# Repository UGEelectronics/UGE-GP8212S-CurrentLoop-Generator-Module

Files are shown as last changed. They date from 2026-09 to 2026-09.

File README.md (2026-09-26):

# UGE GP8212S 4–20 mA Current Loop Generator Module

Compact **I²C-controlled** analog output board based on the Linearin **GP8212S-TC50-EW** (15-bit DAC → industrial **0 / 4–20 mA** current loop).

**[Open interactive BOM ↗](https://ugeelectronics.github.io/UGE-GP8212S-CurrentLoop-Generator-Module/GP8212SBOM.html)** — browser BOM for soldering / identifying parts (do not use the GitHub `.html` file viewer).

<p align="center">
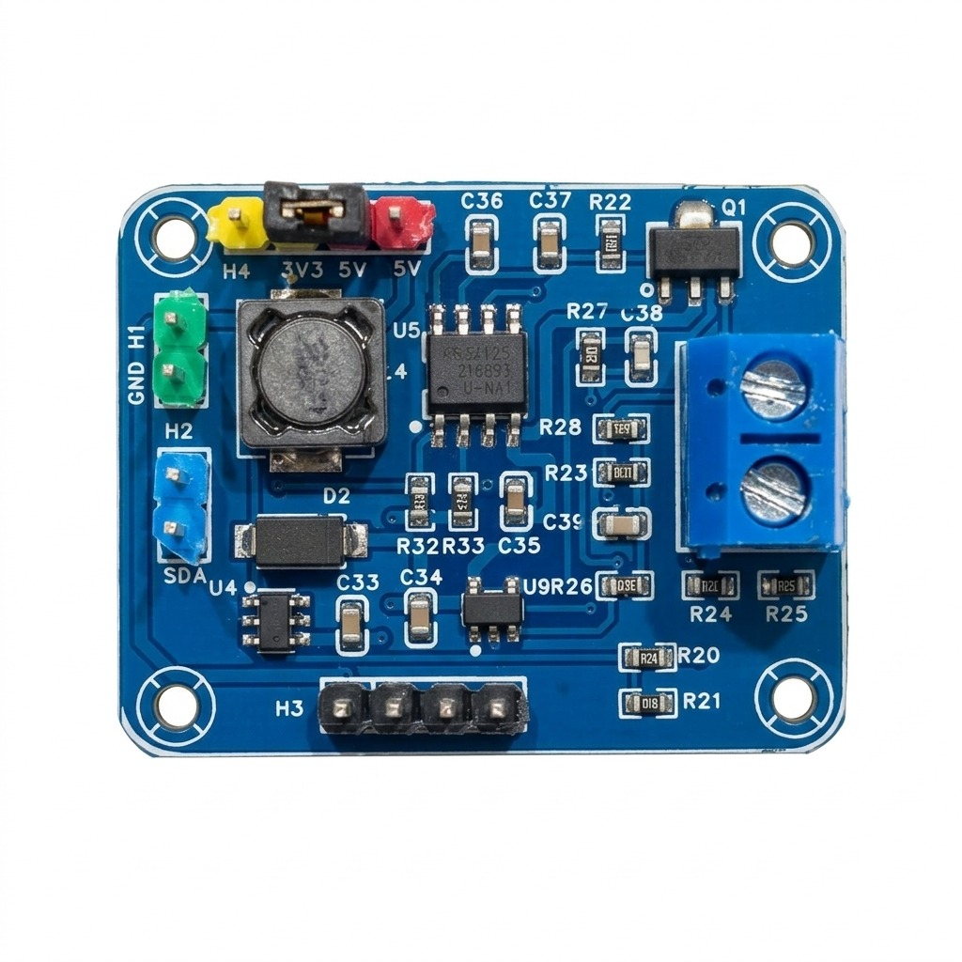
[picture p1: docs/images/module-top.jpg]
UGE GP8212S module top view
  
</p>

<p align="center">
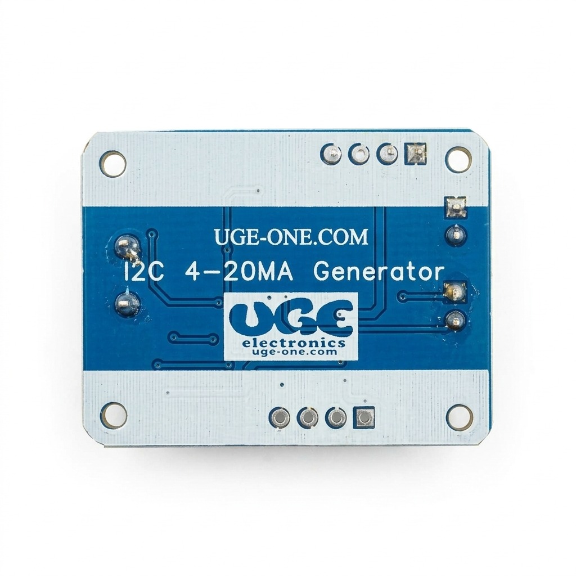
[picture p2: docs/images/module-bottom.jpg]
UGE GP8212S module bottom — I2C 4-20mA Generator
  
</p>

| | |
|---|---|
| **Chip** | GP8212S-TC50-EW (ESOP-8), 15-bit I²C |
| **Output** | 0–25 mA full scale (typical with Rs = 100 Ω); use 4–20 mA for industrial loops |
| **Interface** | I²C address **0x58**, logic **2.7–5.5 V** (Arduino & ESP32 friendly) |
| **Module power** | **5 V** input → onboard **MT3608** boost → ~**12 V** for the DAC |
| **MCU examples** | Arduino / ESP32 library in this repo; STM32 bit-bang reference included |
| **Interactive BOM** | **[Open in browser](https://ugeelectronics.github.io/UGE-GP8212S-CurrentLoop-Generator-Module/GP8212SBOM.html)** |
| **Buy the full module** | **[uge-one.com](https://uge-one.com/product/gp8212s-4-20-ma-current-loop-generator-transmitter-i2c-module/)** |

---

## Buy

| Item | Link |
|---|---|
| **Full module (assembled)** | [uge-one.com — GP8212S 4–20 mA I2C module](https://uge-one.com/product/gp8212s-4-20-ma-current-loop-generator-transmitter-i2c-module/) |
| **GP8212S chip only** | [uge-one.com — GP8212S-TC50-EW](https://uge-one.com/product/gp8212s-tc50-ew-15-bit-i%c2%b2c-to-4-20ma-dac-ic-esop-8/) |
| **Empty bare PCB** | [uge-one.com — PCB for I2C 4–20 mA generator](https://uge-one.com/product/pcb-for-i2c-4-20ma-generator-module/) |
| **Interactive BOM** | **[Open live BOM](https://ugeelectronics.github.io/UGE-GP8212S-CurrentLoop-Generator-Module/GP8212SBOM.html)** |

SKU of the full module: **GP8212S-MOD**. More products: [UGE Electronics](https://uge-one.com/).

---

## Repository layout

```text
software/GP8212S/     Arduino & ESP32 library + examples
docs/                 GitHub Pages site + interactive BOM + images
hardware/             Link to the live BOM (GitHub code view cannot render HTML)
stm32_reference/      Original STM32F10x bit-bang I²C (MyI2C)
```

---

## Quick start (Arduino / ESP32)

### 1. Install the library

**Option A — manual**

1. Download this repository (Code → Download ZIP) or clone it.
2. Copy the folder `software/GP8212S` into your Arduino libraries directory:
   - Windows: `Documents\Arduino\libraries\GP8212S`
   - macOS: `~/Documents/Arduino/libraries/GP8212S`
   - Linux: `~/Arduino/libraries/GP8212S`
3. Restart the Arduino IDE.

**Option B — ZIP**

Sketch → Include Library → Add .ZIP Library… and select a ZIP that contains the `GP8212S` folder (with `library.properties` at its root).

### 2. Wire the module

<p align="center">
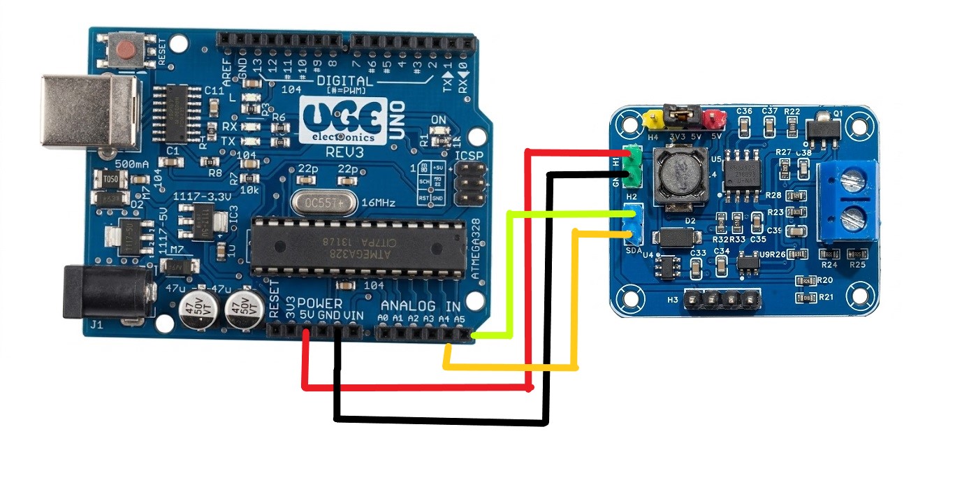
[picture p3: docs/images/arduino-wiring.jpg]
Arduino Uno wired to UGE GP8212S module
  
</p>

| Module | Arduino Uno / Nano | ESP32 (typical) | Notes |
|---|---|---|---|
| **5 V** (H1) | 5 V | 5 V-capable supply | Powers MT3608 → ~12 V for the DAC |
| **GND** (H1) | GND | GND | Common ground |
| **SCL** (H2) | A5 | GPIO 22 | I²C clock |
| **SDA** (H2) | A4 | GPIO 21 | I²C data |
| **IOUT** (blue terminal) | — | — | Loop output — connect load / meter here |

- Share **GND** between MCU and module.
- Do **not** feed the GP8212S chip `VCC` pin from USB 5 V directly — use the module’s **5 V** input so the MT3608 can boost to ~12 V.
- I²C works at **3.3 V** (ESP32) or **5 V** (classic Arduino).

<p align="center">
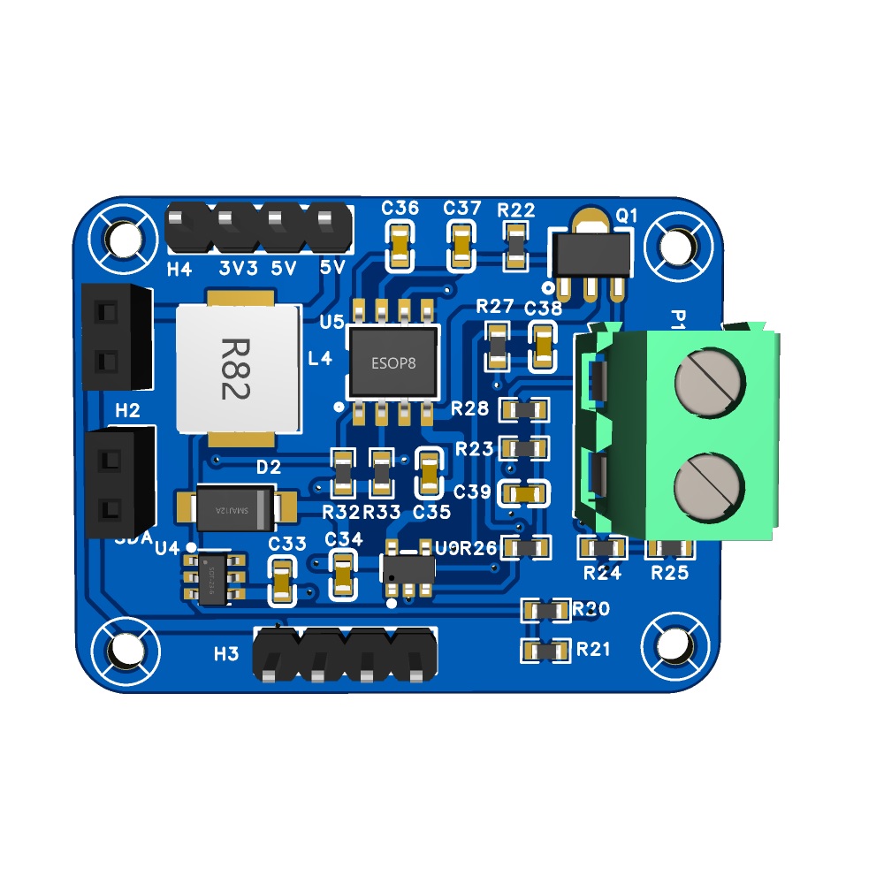
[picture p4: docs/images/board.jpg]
Assembled module overview
  
</p>

### 3. Minimal sketch

```cpp
#include <Wire.h>
#include <GP8212S.h>

GP8212S dac;  // I2C 0x58, 25 mA full scale (Rs = 100 Ω)

void setup() {
  Serial.begin(115200);

#if defined(ESP32)
  if (dac.begin(21, 22) != 0) {   // SDA, SCL
#else
  if (dac.begin() != 0) {
#endif
    Serial.println("GP8212S not found");
    while (true) {}
  }

  dac.setCurrent_mA(12.0);     // milliamps
  // After one-time calibration, paste your line from "apply":
  // dac.calibrate4_20(5200, 26200);
  // dac.setPercent4_20(50);   // 0–100% of 4–20 mA span
  // dac.setDAC(0x3D70);       // raw 15-bit code
}

void loop() {}
```

### 4. Examples

After install: **File → Examples → GP8212S**

| Example | What it does |
|---|---|
| **CurrentSweep** | Sweeps 4 → 20 → 4 mA |
| **SetAndStore** | Set mA from Serial; optional NVM `store()` |
| **Calibrate4_20** | Interactive two-point calibration with a meter |

---

## API overview

| Method | Description |
|---|---|
| `begin(sda, scl, freq)` | Init I²C and probe (returns `0` on ACK) |
| `setCurrent_mA(mA)` | Output current in mA (0 … full scale) |
| `setPercent4_20(pct)` | 0% → 4 mA, 100% → 20 mA |
| `setDAC(code)` | Raw 15-bit code `0 … 0x7FFF` |
| `calibrate4_20(dac4, dac20)` | Use measured codes for accurate 4–20 mA |
| `store(sda, scl)` | Save last DAC value in chip NVM (survives power-off) |

Ideal codes with **Rs = 100 Ω** (0–25 mA full scale):

| Current | Approx. DAC |
|---|---|
| 4 mA | 5243 (`0x147A`) |
| 12 mA | 15728 (`0x3D70`) |
| 20 mA | 26214 (`0x6666`) |
| 25 mA | 32767 (`0x7FFF`) |

Datasheet: `IOUT = (2.5 V / Rs) × (DATA / 0x7FFF)`.

---

## Calibration (recommended — once per board)

You do **not** repeat this on every power-on. Run it once, then paste `dac.calibrate4_20(...)` into your sketches.

### What you need

- Arduino (or ESP32) + this module wired as above  
- **~330 Ω** load on the blue **IOUT** terminal (**1 W preferred**)  
- DMM measuring the **actual loop current** through that resistor  

### Steps

1. Upload **Examples → GP8212S → Calibrate4_20**.
2. Open **Serial Monitor** at **115200** (line ending: **Newline**).
3. Type **`4`**  
   Read the meter (example: **8.08 mA**).  
   Type **`M 8.08`** — the sketch rescales to 4 mA and **auto-saves** the 4 mA point.
4. Type **`20`**  
   Read the meter (example: **25.63 mA**).  
   Type **`M 25.63`** — rescales to 20 mA and **auto-saves** the 20 mA point.
5. Type **`apply`**. You get a line like:

```cpp
dac.calibrate4_20(5200, 26200);
```

6. Put that line in `setup()` **after** `dac.begin(...)` in all future code for this board.

Optional fine trim before `apply`: `+++` `---` (±2000), `++` `--` (±500), `+` `-` (±50), `]` `[` (±5). Commands are case-insensitive (`m` / `M`).
---

## Hardware & soldering

<p align="center">
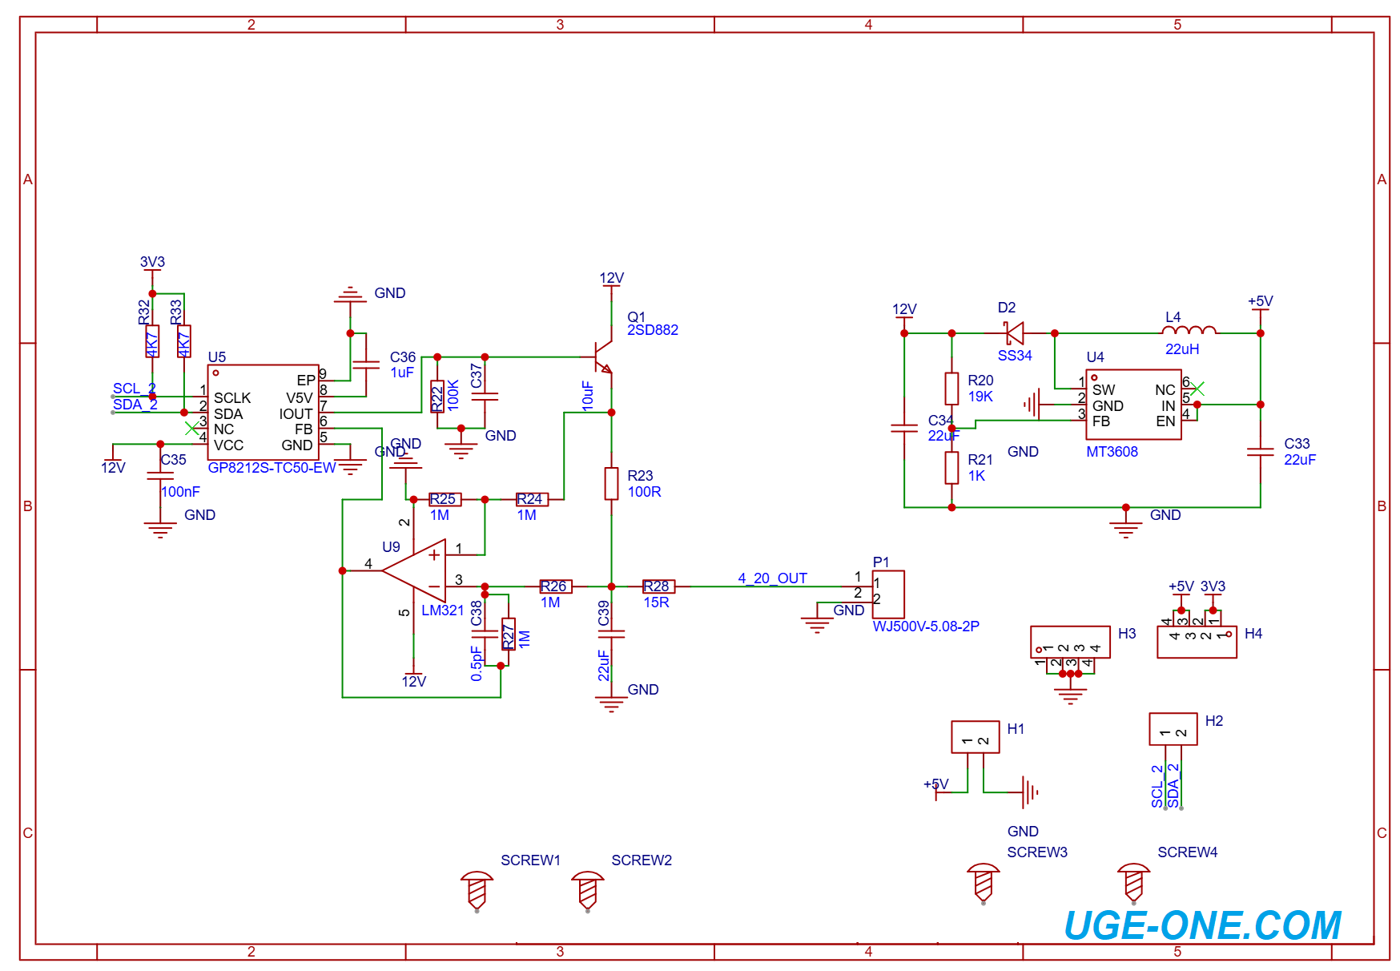
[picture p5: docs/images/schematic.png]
GP8212S module schematic
  
</p>

### Interactive BOM (opens in the browser)

GitHub’s file viewer only shows HTML **source**. Use one of these instead:

| | |
|---|---|
| **Live page (recommended)** | [Open interactive BOM](https://ugeelectronics.github.io/UGE-GP8212S-CurrentLoop-Generator-Module/GP8212SBOM.html) |
| **Docs home** | [ugeelectronics.github.io/…/](https://ugeelectronics.github.io/UGE-GP8212S-CurrentLoop-Generator-Module/) |
| **Offline** | Download [`docs/GP8212SBOM.html`](docs/GP8212SBOM.html) and double-click it |

> **First-time Pages setup (repo admins) — required once:**  
> 1. Open **Settings → Pages**  
> 2. Under **Build and deployment → Source**, choose **Deploy from a branch**  
> 3. Branch: **main**, folder: **/docs** → **Save**  
> 4. Wait about a minute, then open the live BOM link above.

---

## STM32 reference

[`stm32_reference/MyI2C.c`](stm32_reference/MyI2C.c) is the original **STM32F10x open-drain bit-bang I²C** layer (no high-level DAC API). The Arduino library replaces that with `Wire` and implements the GP8212S register write / store sequence.

---

## Notes & limits

- Default I²C address: **`0x58`**.
- Chip `VCC` range per datasheet: **9–36 V**; this module uses ~**12 V** from MT3608 after **5 V** input.
- Max load resistance shrinks at 12 V vs 24 V — keep calibration / field loads in the **~220–330 Ω** range unless you raise the boost voltage within safe design limits.
- There is **no official Arduino library named GP8212S** from the chip vendor; DFRobot’s [GP8XXX](https://github.com/DFRobot/DFRobot_GP8XXX) covers related parts (e.g. GP8211S / GP8302) but not this module. Use **UGE `GP8212S`** here.

---

## License

MIT — see [LICENSE](LICENSE).  
© 2026 UGE Electronics — [uge-one.com](https://uge-one.com/)

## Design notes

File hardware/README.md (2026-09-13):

# Hardware

The interactive BOM is published as a **live web page** (GitHub does not render `.html` files in the code viewer).

**Open here:**  
https://ugeelectronics.github.io/UGE-GP8212S-CurrentLoop-Generator-Module/GP8212SBOM.html

Source file in this repo: [`docs/GP8212SBOM.html`](../docs/GP8212SBOM.html)  
(You can also download that file and open it locally in any browser.)

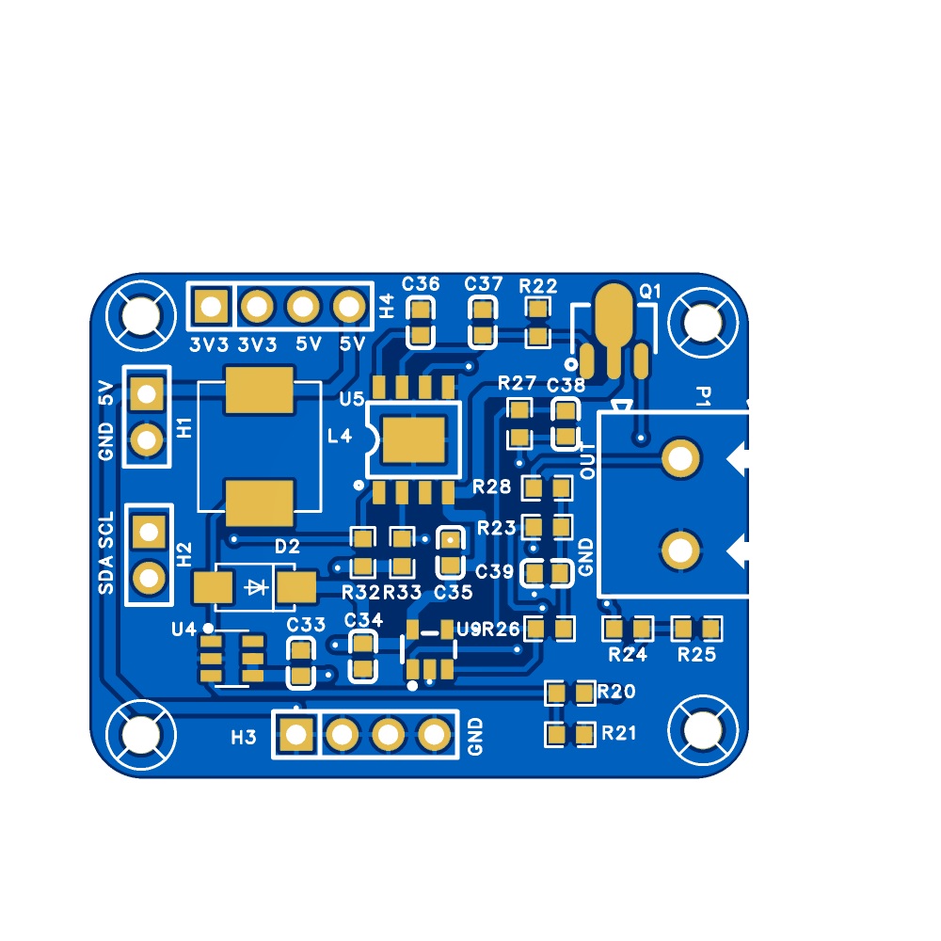
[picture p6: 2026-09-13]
docs/images/pcb-top.jpg

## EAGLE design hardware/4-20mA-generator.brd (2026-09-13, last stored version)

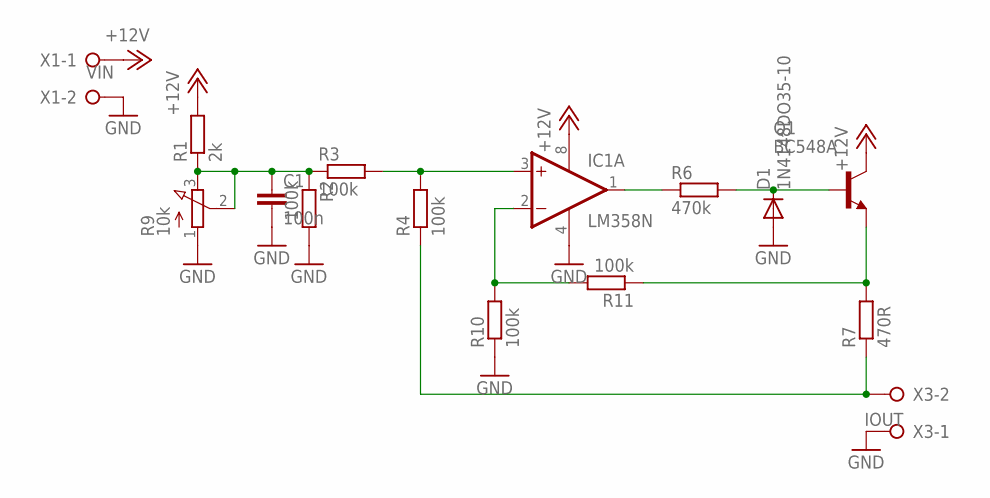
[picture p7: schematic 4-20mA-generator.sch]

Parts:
C1: 100n; C050-024X044
D1: 1N4148DO35-10; DO35-10
IC1: LM358N; DIL08
Q1: BC548A; TO92-EBC
R1: 2k; 0207/7
R2, R3, R4, R10, R11: 100k; 0207/7
R6: 470k; 0207/7
R7: 470R; 0207/7
R9: 10k; 3RP/1610N
X1: VIN; W237-132
X3: IOUT; W237-132

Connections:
+12V: IC1.8 (V+), Q1.C, R1.2, X1.1
GND: C1.2, D1.A, IC1.4 (V-), R2.2, R9.1 (A), R10.1, X1.2, X3.1
unnamed: C1.1, R1.1, R2.1, R3.1, R9.2 (S), R9.3 (E)
unnamed: IC1.2 (-IN), R10.2, R11.2
unnamed: IC1.1 (OUT), R6.1
unnamed: D1.C, Q1.B, R6.2
unnamed: Q1.E, R7.2, R11.1
unnamed: R4.1, R7.1, X3.2
unnamed: IC1.3 (+IN), R3.2, R4.2

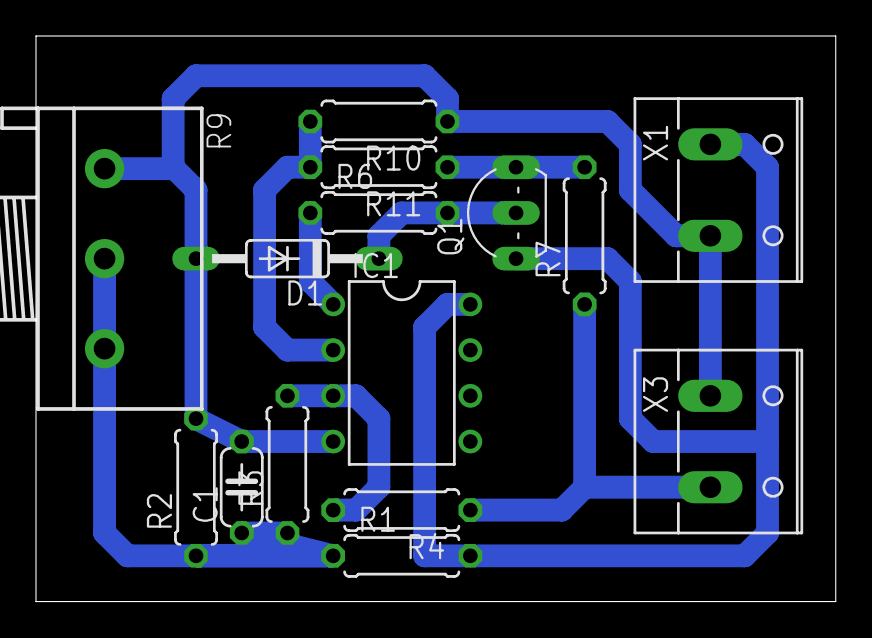
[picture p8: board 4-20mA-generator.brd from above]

Board: 2 copper layers, 44.4 x 31.4 mm, 15 parts (0 on the bottom side), 9 nets.

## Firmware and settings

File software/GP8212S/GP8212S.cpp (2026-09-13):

/*!
 * @file GP8212S.cpp
 * @brief Arduino / ESP32 driver for Linearin GP8212S
 */

#include "GP8212S.h"

const float GP8212S::FULL_SCALE_MA = 25.0f;

// Register / store timing constants (same GP8xxx family protocol as DFRobot)
static const uint8_t REG_DAC = 0x02;
static const uint8_t STORE_HEAD = 0x02;   // 3-bit preamble
static const uint8_t STORE_ADDR = 0x10;
static const uint8_t STORE_CMD1 = 0x03;
static const uint8_t STORE_CMD2 = 0x00;
static const uint8_t STORE_DELAY_MS = 10;

static const uint8_t I2C_HALF_US = 5;

GP8212S::GP8212S(uint8_t deviceAddr, TwoWire *wire, float fullScaleMa)
    : _wire(wire),
      _addr(deviceAddr),
      _fullScaleMa(fullScaleMa),
      _lastDac(0),
      _calEnabled(false),
      _cal4(0),
      _cal20(0),
      _sdaPin(-1),
      _sclPin(-1) {}

int GP8212S::begin(int sda, int scl, uint32_t freq) {
  _sdaPin = sda;
  _sclPin = scl;

#if defined(ESP32) || defined(ESP8266) || defined(ARDUINO_ARCH_ESP32)
  if (sda >= 0 && scl >= 0) {
    _wire->begin(sda, scl, freq);
  } else {
    _wire->begin();
    _wire->setClock(freq);
  }
#else
  (void)sda;
  (void)scl;
  _wire->begin();
  _wire->setClock(freq);
#endif

  _wire->beginTransmission(_addr);
  return _wire->endTransmission();
}

bool GP8212S::isConnected() {
  _wire->beginTransmission(_addr);
  return _wire->endTransmission() == 0;
}

uint16_t GP8212S::mAToDAC(float mA) const {
  if (mA <= 0.0f) {
    return 0;
  }
  if (mA >= _fullScaleMa) {
    return DAC_MAX;
  }
  return (uint16_t)((mA / _fullScaleMa) * (float)DAC_MAX + 0.5f);
}

float GP8212S::dacTo_mA(uint16_t code) const {
  if (code > DAC_MAX) {
    code = DAC_MAX;
  }
  return ((float)code / (float)DAC_MAX) * _fullScaleMa;
}

void GP8212S::calibrate4_20(uint16_t dacAt4mA, uint16_t dacAt20mA) {
  if (dacAt4mA >= dacAt20mA || dacAt20mA > DAC_MAX) {
    _calEnabled = false;
    return;
  }
  _cal4 = dacAt4mA;
  _cal20 = dacAt20mA;
  _calEnabled = true;
}

void GP8212S::clearCalibration() {
  _calEnabled = false;
}

bool GP8212S::writeDACRegister(uint16_t shifted16) {
  // Protocol: START | ADDR+W | REG=0x02 | DATA_LOW | DATA_HIGH | STOP
  // 15-bit payload is left-shifted by 1 before the two data bytes.
  uint8_t lo = (uint8_t)(shifted16 & 0xFF);
  uint8_t hi = (uint8_t)(shifted16 >> 8);

  _wire->beginTransmission(_addr);
  _wire->write(REG_DAC);
  _wire->write(lo);
  _wire->write(hi);
  return _wire->endTransmission() == 0;
}

bool GP8212S::setDAC(uint16_t code) {
  if (code > DAC_MAX) {
    code = DAC_MAX;
  }
  _lastDac = code;
  // Same packing as GP8211S / GP8xxx 15-bit parts
  return writeDACRegister((uint16_t)(code << 1));
}

uint16_t GP8212S::setCurrent_mA(float mA) {
  uint16_t code;

  if (_calEnabled && mA >= 4.0f && mA <= 20.0f) {
    // Linear map 4–20 mA onto measured DAC codes
    float t = (mA - 4.0f) / 16.0f;
    code = (uint16_t)(_cal4 + t * (float)(_cal20 - _cal4) + 0.5f);
  } else {
    code = mAToDAC(mA);
  }

  if (!setDAC(code)) {
    return 0xFFFF;
  }
  return code;
}

uint16_t GP8212S::setPercent4_20(float percent) {
  if (percent < 0.0f) {
    percent = 0.0f;
  }
  if (percent > 100.0f) {
    percent = 100.0f;
  }
  return setCurrent_mA(4.0f + percent * 0.16f);
}

// ---- NVM store (datasheet §3.2.4) — bit-bang on the same pins ----

void GP8212S::storeStart(int scl, int sda) {
  digitalWrite(scl, HIGH);
  digitalWrite(sda, HIGH);
  delayMicroseconds(I2C_HALF_US);
  digitalWrite(sda, LOW);
  delayMicroseconds(I2C_HALF_US);
  digitalWrite(scl, LOW);
  delayMicroseconds(I2C_HALF_US);
}

void GP8212S::storeStop(int scl, int sda) {
  digitalWrite(sda, LOW);
  delayMicroseconds(I2C_HALF_US);
  digitalWrite(scl, HIGH);
  delayMicroseconds(I2C_HALF_US);
  digitalWrite(sda, HIGH);
  delayMicroseconds(I2C_HALF_US);
}

uint8_t GP8212S::storeSendByte(int scl, int sda, uint8_t data, uint8_t bits,
                               bool expectAck) {
  for (int i = bits - 1; i >= 0; i--) {
    digitalWrite(sda, (data & (1 << i)) ? HIGH : LOW);
    delayMicroseconds(I2C_HALF_US);
    digitalWrite(scl, HIGH);
    delayMicroseconds(I2C_HALF_US);
    digitalWrite(scl, LOW);
    delayMicroseconds(I2C_HALF_US);
  }

  if (!expectAck) {
    digitalWrite(sda, LOW);
    digitalWrite(scl, HIGH);
    delayMicroseconds(I2C_HALF_US);
    digitalWrite(scl, LOW);
    return 0;
  }

  pinMode(sda, INPUT_PULLUP);
  delayMicroseconds(I2C_HALF_US);
  digitalWrite(scl, HIGH);
  delayMicroseconds(I2C_HALF_US);
  uint8_t ack = digitalRead(sda);
  digitalWrite(scl, LOW);
  delayMicroseconds(I2C_HALF_US);
  pinMode(sda, OUTPUT);
  return ack;
}

void GP8212S::store(int sda, int scl) {
  if (sda < 0) {
    sda = _sdaPin;
  }
  if (scl < 0) {
    scl = _sclPin;
  }
  if (sda < 0 || scl < 0) {
    // Fall back to Arduino default macros when pins were never passed to begin()
#if defined(SDA) && defined(SCL)
    sda = SDA;
    scl = SCL;
#else
    return;
#endif
  }

#if defined(ESP32)
  _wire->~TwoWire();
#elif !defined(ESP8266)
  _wire->end();
#endif

  pinMode(scl, OUTPUT);
  pinMode(sda, OUTPUT);
  digitalWrite(scl, HIGH);
  digitalWrite(sda, HIGH);

  // Sequence from datasheet / GP8xxx store timing
  storeStart(scl, sda);
  storeSendByte(scl, sda, STORE_HEAD, 3, false);
  storeStop(scl, sda);

  storeStart(scl, sda);
  storeSendByte(scl, sda, STORE_ADDR);
  storeSendByte(scl, sda, STORE_CMD1);
  storeStop(scl, sda);

  storeStart(scl, sda);
  storeSendByte(scl, sda, (uint8_t)(_addr << 1));
  for (int i = 0; i < 8; i++) {
    storeSendByte(scl, sda, STORE_CMD2);
  }
  storeStop(scl, sda);

  delay(STORE_DELAY_MS);

  storeStart(scl, sda);
  storeSendByte(scl, sda, STORE_HEAD, 3, false);
  storeStop(scl, sda);

  storeStart(scl, sda);
  storeSendByte(scl, sda, STORE_ADDR);
  storeSendByte(scl, sda, STORE_CMD2);
  storeStop(scl, sda);

  // Restore hardware I2C
#if defined(ESP32) || defined(ESP8266) || defined(ARDUINO_ARCH_ESP32)
  if (_sdaPin >= 0 && _sclPin >= 0) {
    _wire->begin(_sdaPin, _sclPin);
  } else {
    _wire->begin();
  }
#else
  _wire->begin();
#endif
}

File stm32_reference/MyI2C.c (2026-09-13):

#include "stm32f10x.h"                  // Device header
#include "delay.h"

void MyI2C_W_SCL(uint8_t BitValue)
{
	GPIO_WriteBit(GPIOA, GPIO_Pin_2, (BitAction)BitValue);
	Delay_us(10);
}

void MyI2C_W_SDA(uint8_t BitValue)
{
	GPIO_WriteBit(GPIOA, GPIO_Pin_3, (BitAction)BitValue);
	Delay_us(10);
}

uint8_t MyI2C_R_SDA(void)
{
	uint8_t BitValue;
	BitValue = GPIO_ReadInputDataBit(GPIOA, GPIO_Pin_3);
	Delay_us(10);
	return BitValue;
}

void MyI2C_Init(void)
{
	GPIO_InitTypeDef GPIO_InitStructure;
	
	RCC_APB2PeriphClockCmd(RCC_APB2Periph_GPIOA, ENABLE);
	
	GPIO_InitStructure.GPIO_Mode = GPIO_Mode_Out_OD;
	GPIO_InitStructure.GPIO_Pin = GPIO_Pin_2 | GPIO_Pin_3;
	GPIO_InitStructure.GPIO_Speed = GPIO_Speed_50MHz;
	GPIO_Init(GPIOA, &GPIO_InitStructure);
	
	GPIO_SetBits(GPIOA, GPIO_Pin_2 | GPIO_Pin_3);
}

void MyI2C_Start(void)
{
	MyI2C_W_SDA(1);
	MyI2C_W_SCL(1);
	MyI2C_W_SDA(0);
	MyI2C_W_SCL(0);
}

void MyI2C_Stop(void)
{
	MyI2C_W_SDA(0);
	MyI2C_W_SCL(1);
	MyI2C_W_SDA(1);
}

void MyI2C_SendByte(uint8_t Byte)
{
	uint8_t i;
	for (i = 0; i < 8; i ++)
	{
		MyI2C_W_SDA(Byte & (0x80 >> i));
		MyI2C_W_SCL(1);
		MyI2C_W_SCL(0);
	}
}

uint8_t MyI2C_ReceiveByte(void)
{
	uint8_t i, Byte = 0x00;
	MyI2C_W_SDA(1);
	for (i = 0; i < 8; i ++)
	{
		MyI2C_W_SCL(1);
		if (MyI2C_R_SDA() == 1){Byte |= (0x80 >> i);}
		MyI2C_W_SCL(0);
	}
	return Byte;
}

void MyI2C_SendAck(uint8_t AckBit)
{
	MyI2C_W_SDA(AckBit);
	MyI2C_W_SCL(1);
	MyI2C_W_SCL(0);
}

uint8_t MyI2C_ReceiveAck(void)
{
	uint8_t AckBit;
	MyI2C_W_SDA(1);
	MyI2C_W_SCL(1);
	AckBit = MyI2C_R_SDA();
	MyI2C_W_SCL(0);
	return AckBit;
}



void GP8212_W_SCL(uint8_t BitValue)
{
	GPIO_WriteBit(GPIOA, GPIO_Pin_9, (BitAction)BitValue);
	Delay_us(10);
}

void GP8212_W_SDA(uint8_t BitValue)
{
	GPIO_WriteBit(GPIOA, GPIO_Pin_8, (BitAction)BitValue);
	Delay_us(10);
}

uint8_t GP8212_R_SDA(void)
{
	uint8_t BitValue;
	BitValue = GPIO_ReadInputDataBit(GPIOA, GPIO_Pin_8);
	Delay_us(10);
	return BitValue;
}

void GP8212_Init(void)
{
	GPIO_InitTypeDef GPIO_InitStructure;
	
	RCC_APB2PeriphClockCmd(RCC_APB2Periph_GPIOA, ENABLE);
	
	GPIO_InitStructure.GPIO_Mode = GPIO_Mode_Out_OD;
	GPIO_InitStructure.GPIO_Pin = GPIO_Pin_8 | GPIO_Pin_9;
	GPIO_InitStructure.GPIO_Speed = GPIO_Speed_50MHz;
	GPIO_Init(GPIOA, &GPIO_InitStructure);
	
	GPIO_SetBits(GPIOA, GPIO_Pin_8 | GPIO_Pin_9);
}

void GP8212_Start(void)
{
	GP8212_W_SDA(1);
	GP8212_W_SCL(1);
	GP8212_W_SDA(0);
	GP8212_W_SCL(0);
}

void GP8212_Stop(void)
{
	GP8212_W_SDA(0);
	GP8212_W_SCL(1);
	GP8212_W_SDA(1);
}

void GP8212_SendByte(uint8_t Byte)
{
	uint8_t i;
	for (i = 0; i < 8; i ++)
	{
		GP8212_W_SDA(Byte & (0x80 >> i));
		GP8212_W_SCL(1);
		GP8212_W_SCL(0);
	}
}

uint8_t GP8212_ReceiveByte(void)
{
	uint8_t i, Byte = 0x00;
	GP8212_W_SDA(1);
	for (i = 0; i < 8; i ++)
	{
		GP8212_W_SCL(1);
		if (GP8212_R_SDA() == 1){Byte |= (0x80 >> i);}
		GP8212_W_SCL(0);
	}
	return Byte;
}

void GP8212_SendAck(uint8_t AckBit)
{
	GP8212_W_SDA(AckBit);
	GP8212_W_SCL(1);
	GP8212_W_SCL(0);
}

uint8_t GP8212_ReceiveAck(void)
{
	uint8_t AckBit;
	GP8212_W_SDA(1);
	GP8212_W_SCL(1);
	AckBit = MyI2C_R_SDA();
	GP8212_W_SCL(0);
	return AckBit;
}

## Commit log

2026-09-13 Add Arduino/ESP32 library, docs, hardware BOM, and module guide.
    Publish GP8212S driver with examples, board images, interactive BOM, and buy links so users can assemble and drive the UGE 4-20 mA module.
    [4-20mA-generator.brd, 4-20mA-generator.sch]
2026-09-13 Remove unrelated Eagle schematic and board files.
    Keep only the interactive BOM under hardware/ for this module repo.
    [4-20mA-generator.brd, 4-20mA-generator.sch]
2026-09-13 Serve interactive BOM via GitHub Pages instead of the code viewer.
    Move the HTML under docs/, add a Pages deploy workflow, and link the live URL so the BOM opens as a page rather than raw source.
2026-09-13 Document branch-based GitHub Pages setup for the interactive BOM.
    Replace outdated Actions instructions after Configure Pages failed.
2026-09-13 Highlight the live interactive BOM link at the top of the README.
    Make the GitHub Pages BOM URL easy to find for users soldering the board.
2026-09-23 Make 4-20 mA calibration usable when ideal codes overshoot.
    Add meter rescale (m <reading>), large DAC steps, and start the 20 mA jump below full-scale so users are not stuck tapping minus.
    [Calibrate4_20.ino]
2026-09-24 Document the simple 4 / M / 20 / M / apply calibration flow and add module photos.
    Match the Calibrate4_20 sketch to that workflow (auto-save on M, accept 20), and publish wiring plus top/bottom images in the README.
2026-09-26 Add the full assembled module product page to the buy links.
    Point users to the UGE-ONE GP8212S 4-20 mA I2C module listing from the README and docs home.
